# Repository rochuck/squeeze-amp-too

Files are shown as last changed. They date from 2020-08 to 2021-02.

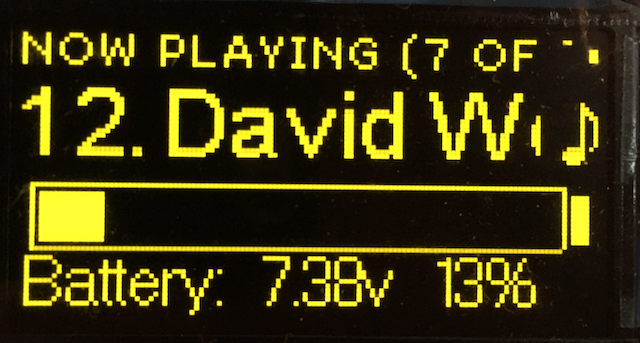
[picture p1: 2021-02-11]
images/bat_gauge.png

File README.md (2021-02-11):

# SqueezeAmpToo: an all-in-one audio sub-system

The SqueezeAmpToo is designed by Dave Viberg and Chuck Rohs and was completely inspired by the [SqueezeAMP project](https://github.com/philippe44/SqueezeAMP) and the [SqueezeESP project](https://github.com/philippe44/squeezelite-esp32).

While this project borrows a lot from the SqueezeAmp, it has some differences for both reduced cost and added functionality. These include:
* only 2 cells supported for reduced power consumption/heat.
* larger board to add a better performing 1 inch <sup>2</sup> heat sink for 16V operation. The board is now basically the size of a dual 18650 battery pack.
* a cost reduced charger and buck regulator
* onboard USB to serial interface for easy initial programming along with a JTAG port.
* V2 fixes a charger wiring error, low voltage cutoff for 3.3v buck, headphone and powerjack footprints.
* V2 adds an optional spi display header, rotary encoder and button board with an I2C expander, a daughter board to drive ws2812s, a battery pack thermister, and IR remote control daughter board.

The squeeze amp board is running in the box show below.  To run this board, in particular the RGB LEDs and I2C buttons on the gpio expander, the [SqueezeAmpToo Software](https://github.com/rochuck/squeezelite-esp32/tree/squeezetoo) should be used. This software is a fork of the SqueezeEsp project referenced above.

The RGB LEDS are illustrated in the animated GIF (it will only loop once in certain browsers, click on the image to see it in action if it isn't animating). This little box has 31 ws2812's (144 leds/meter density) along with the very nice/quasi expensive ssd1322 256 x 64 OLED.  While the leds might be a little bit hokey, the center led changed color to indicate the battery voltage. This is all described in the [Readme](https://github.com/rochuck/squeezelite-esp32/blob/squeezetoo/README.md).

 LED VU meters

# Future Plans
We've got a [PurePath Console Motherboard](https://www.ti.com/tool/PUREPATH-CMBEVM) board on order, so we can use the onboard DSP of the TAS chip.  This will allow us to stop messing with the equalizer running on the ESP and hopefully tune the stereos to get the most out of the speakers. 

We've done some playing around with a mono version of the board.  It is easy to hack to make it work that way, but again, the purepath software is probably required to do a proper job of it.

# Doc Packages,Gerbers, BOM, and Software
We're using Protel 99SE for schematics and routing. The current version, V2, files are here, use at your own risk, we have not yet done a board run on these files. Also if you use them, please give credit to Dave Viberg, Chuck Rohs, and [philippe44](https://github.com/philippe44) from whom we leveraged the initial schematics. Standing on the shoulders of giants and all that....

 V2 SqueezeAmpToo Doc Package

 V4 DaughterBoards Doc Package

 The [CAM PACKAGE](https://github.com/rochuck/squeeze-amp-too/tree/master/CAM-SqueezeAmpTooV2-panel-url) is here.

 The [BOM](https://github.com/rochuck/squeeze-amp-too/blob/master/SqueezeAmpTooV1-BOM.xlsx) is here. Note however this is the V1 BOM. It does not contain the daughterboard parts, But should get you started.

 As stated above Software is [here](https://github.com/rochuck/squeezelite-esp32/tree/squeezetoo) and [here](https://github.com/rochuck/squeezelite-esp32/releases/tag/0.0.6-rgb-led-update-v4.0-SqueezeToo-squeezetoo).

## Errata
The pinouts for the IR receiver are wrong.  Pins 2 and 3 are transposed.

# History

This project started out from experimenting with the squeezeamp software. I first got it working with a [HiFiBerry]( https://www.hifiberry.com/docs/archive/connecting-power-supply-and-speakers-to-the-hifiberry-amp/) clone. From there it got out of hand and we started building hardware and modifying software and ended up with the current generation board. 

## HiFiBerry Prototype
This design was prototyped using the squeezelite-esp32 code on a WROVER board that was fly-wired to a clone of the HiFiBerry AMP+. This audio board uses the TAS5713, and as such an appropriate driver needed to be written to use the squeezelite-esp32 code. That is now all ancient history but the picture and development is documented here for posterity (covered in CNC router dust):

  HifiBerry with SqueezeESP

For anyone else wanting to replicate this configuration, The WROVER is hooked up to the HiFiBerry as follows:

|WROVER Pin#|HiFiBerry 40pin connector number|Function|
|----|----|---|
|8|40|I2S-SD|
|9|12|I2S-CLK|
|10|35|I2S-LRCLK|
|11|5|I2C-SCL|
|12|3|I2C-SDA|
|1|6|GND|

Depending on your dev board, you may be able to pull power from the pi amp, but I would recommend separate power supplies, and just tie the grounds together.

As of this writing [sle118's repo](https://github.com/sle118/squeezelite-esp32/tree/c78c66faf57f0aea6eb86f7e74e01c9b28b824be) contains the TAS5713 driver I developed.
To test this out I used the sdkconfig "SqueezeAmp8MBFlash-sdkconfig.defaults". 
The code [here](https://github.com/sle118/squeezelite-esp32/blob/c78c66faf57f0aea6eb86f7e74e01c9b28b824be/components/squeezelite/output_i2s.c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)
was modified to replace "CONFIG_DAC_CONFIG" with "NULL"
so that the dac_config NVS parameter would not be overridden.

The dac_config was set to:
  - model=TAS5713,bck=33,ws=25,do=32,sda=27,scl=26

Also note that the partition map needed to be changed so that the OTA application resides at 0x160000.

## Squeeze Amp Too V1 Prototype
Since then, the V1 squeeze-amp-too has been built, and while there are a few errors, it performs remarkably well. The (modified for mono) V1 board is pictured here:

 squeeze-amp-too v1

It includes the following:

- Espressif's WROVER board based on ESP32 WiFi/BT chipset (built-in antenna)
- WiFi / BT connectivity
- TI's TAS575x stereo class-D amplifier for up to 2x20W
- 1"^2 heatsink to handle the TAS and WROVER heat
- Built-in battery charger 2 Li-ion cells in series and automatic switch between battery and external power
- Direct speaker output
- Jack 3.5mm for analogue line-out with insertion detection
- SDPIF optical output
- Connectors for GPIO
- Onboard CP2102N for programming, with rx/tx leds. (CP2102 must be programmed with silabs software for the leds to work, i.e. chaning the gpios for alternate functionality)
- Charge LED 
- Two general purpose LEDs (red/green)

Connectors:
- J1 - Power Jack rated for 5A (PJ-047AH)
- J2 - Headphone Jack
- J3 - USB Micro B (for initial programming/debug)
- J4, J9 - Battery connectors
- J10 - .15" header, alt power
- J5, J12 - .15" speaker connectors
- J6, J13 - 5 pin .1" headers, for various gpio.
- J7 - 4 pin .1" header for sh1105 OLED display
- J11 - 6 pin .1" header for JTAG

## What can it do

With the squeezelite-esp32 software, you can (as quoted from the SqueezeAMP)

- Stream from LMS and send audio to the build-in amplifier, the line-out jack, the spdif connector or another bluetooth speaker. You can also use an external I2S DAC if you connect it to the general purpose 5/8 pins connector and tweak the software. Synchronization works.
- Stream from a Bluetooth device and send audio to the same outputs, except of course for sending to another bluetooth speaker ... There is no guarantee of audio/video synchronization at this point
- Stream from an AirPlay1 device (iPhone, iTunes ...) to the same outputs, including to a bluetooth speaker. Synchronization works.
- Add your own buttons, rotary encoder and map/combine them to various functions (play, pause, volume, next ...
- Use IR control by adding a simple receiver compatible with 38kHz device (no pullup resistor or capacitor needed)
- Add a display like this [one](https://www.buydisplay.com/i2c-blue-0-91-inch-oled-display-module-128x32-arduino-raspberry-pi) which can be directly connected to the 6-pins header. Currently, SSD1306, SSD1326/7 and SH1106 displays are supported.
- Support for WS2812 RGB LED VU meters (other coming soon). Supported with a 5v buck converter with enable
- Rotary encoder daughter board with IIC/SPI gpio expanders

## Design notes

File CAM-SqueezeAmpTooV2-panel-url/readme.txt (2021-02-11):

CAM Outputs Generation Report
for 'CAM Outputs for SqueezeAmpTooV2-panel.cam'
at 21:40:26 on 26-Sep-2020

'Pick Place Output 1'
'Pick Place for SqueezeAmpTooV2-panel.txt' generated
'Pick Place for SqueezeAmpTooV2-panel.csv' generated

'NC Drill Output 1'
'SqueezeAmpTooV2-panel.TXT' generated text drill file
'SqueezeAmpTooV2-panel.DRL' generated binary drill file
'SqueezeAmpTooV2-panel.DRR' generated tool list

'Gerber Output 1'
'SqueezeAmpTooV2-panel.GTL' generated top copper
'SqueezeAmpTooV2-panel.GBL' generated bottom copper
'SqueezeAmpTooV2-panel.GTO' generated top silkscreen
'SqueezeAmpTooV2-panel.GBO' generated bottom silkscreen
'SqueezeAmpTooV2-panel.GTP' generated top solder paste
'SqueezeAmpTooV2-panel.GBP' generated bottom solder past
'SqueezeAmpTooV2-panel.GTS' generated top solder mask
'SqueezeAmpTooV2-panel.GBS' generated bottom solder mask
'SqueezeAmpTooV2-panel.GM4' generated board outline
'SqueezeAmpTooV2-panel.GPT' generated top pad master
'SqueezeAmpTooV2-panel.GPB' generated bottom pad master
'SqueezeAmpTooV2-panel.REP' generated

Total number of generated files = 17

Board specification
FR-4 or FR-4 high TG
double sided 1oz. copper
thickness, choose 0.8mm to 1.6mm
trace space 0.006"/0.006"
smallest drill 0.012"
solder mask, any color you want
silkscreen, any color you want

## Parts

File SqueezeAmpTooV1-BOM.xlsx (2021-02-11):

BOM-SqueezeAmpTooV1, David Viberg, May 25, 2020
Used | Part Type | Designator | Footprint | Description | DigiKey
==== | ============== | ========== | ========= | =================== | ==========
Resistors
1 | 0.1R | R17 | 0805 | Resistor sets charging current | 273-KDV08FR100ETCT-ND
1 | 1K | R22 | 0603 | Resistor
10 | 10K | R1 R2 R3 R4 R5 R6 R7 R20 R23 R24 | 0603 | Resistor
1 | 13K | R18 | 0603 | Resistor
1 | 22.1K | R19 | 0603 | Resistor
1 | 40,2K | R16 | 0603 | Resistor
1 | 47.5K | R21 | 0603 | Resistor
1 | 59K | R9 | 0603 | Resistor
2 | 100K | R14 R15 | 0603 | Resistor
1 | 150K | R13 | 0603 | Resistor
1 | 174K | R11 | 0603 | Resistor
1 | 499K | R10 | 0603 | Resistor
1 | 750K | R12 | 0603 | Resistor
1 | 3M | R8 | 0603 | Resistor
Thermister
1 | 10K THERMISTOR | RT1 | 0603 | thermister, ntc | 490-16279-1-ND
Capacitors
1 | 47pF | C38 | 0603 | Capacitor
8 | 100nF | C1 C2 C3 C6 C7 C8 C9 C41 | 0603 | Capacitor
4 | 220nF 25V | C30 C31 C32 C33 | 0603 | Capacitor
4 | 680nF 25V | C34 C35 C36 C37 | 0603 | Capacitor
9 | 1uF 25V | C5 C18 C19 C20 C21 C22 C23 C24 C25 | 0603 | Capacitor
4 | 2.2uF 25V | C26 C27 C28 C29 | 0603 | Capacitor | 490-12738-1-nd
5 | 10uF 16V | C4 C16 C17 C39 C40 | 0603 | Capacitor | 1276-6769-1-ND
6 | 22uF 25V | C10 C11 C12 C13 C14 C15 | 0805 | Capacitor | 311-1903-1-nd
Inductors
4 | 4.7uH 4.5A | L1 L2 L3 L4 | 2424 | Inductor for speaker filters | 2037-sdes064t-4r7msct-nd
2 | 6.8uH 2A | L5 L6 | 2020 | Inductor for charger | 587-3462-1-nd
Diodes
3 | SCHOTTKY 30V 3A | D1 D2 D3 | DO-214AC | Schottky Diode pmeg3030 | 1727-5324-1-nd
3 | red | D4 D5 D6 | 0603D | red LED | generic 200 mcd
2 | grn | D7 D8 | 0603D | green LED | generic 200 mcd
Transistors
3 | mmbt4401 | Q1 Q2 Q3 | SOT-23 | NPN transistor
1 | PFET dmp4065 | Q4 | SOT-23 | MOSFET P SOT-23, 2.4A | DMP4065S-7DICT-ND
Connectors
1 | POWERJACKCOAX | J1 | PJ-047AH | Power Jack COAX, 5A | CP-047AH-ND
1 | SJ-43514 | J2 | SJ-43514 | Headphone jack | CP-43514-ND
1 | USB-MICRO-B-JACK | J3 | USB-MICRO-B-FCI-10118194 | USB micro B jack | 609-4618-1-nd
3 | CON2 | J4 J8 J9 | HDR2 | Connect 2 batteries and switch
3 | CON2 - horizontal | J5 J10 J12 | HDR2-.15 | speaker terminals, alt power | 732-2088-ND
3 | plug for above |  |  | speaker terminals, alt power | 609-3797-ND
2 | CON5 | J6 J13 | HDR5 | Connector for gpio's w pwr gnd | solder pigtails
1 | CON4 | J7 | HDR4 | 4 x 0.1" pin jack for sh1106 oled
1 | CON6 | J11 | HDR6 | Connector for esp32-prog jtag | solder pigtails
Battery
2 | 18650 | J4 J8 |  | 18650 Li Ion cells
1 |  |  |  | dual 18650 battery holder | 1597-114090053-nd
Switches
1 | SW-SPDT | S1 | SW-EG1270 | slide switch | EG1847-ND
1 | SW-PB-GND | S2 | SWKMR2 | push button reset | 401-1427-1-ND
Solder Bridge
1 | Solderbridge | BR1 | solderbridge0.05 | solder bridge to disconnect IRRX when doing JTAG
IC's
1 | TAS5754M | U1 | SSOP-48 | Stereo class D amplifier | 296-40564-1-ND
1 | ESP32-WROVER | U2 | ESP32 | ESP32 dual core micro w wifi | 1904-1034-1-ND
1 | EAPLTAA4 |  | PLT133/T10W | SPDIF transmitter | 1080-1524-ND
1 | AP65111 | U4 | SOT-23-6 | Sync buck, 4-18Vin, 1.5Aout | ap65111awu-7dict-nd
1 | MP2615 | U5 | QFN-16-MPS | 1-2 cell Li-ion battery charger | 1589-1610-1-nd
1 | CP2102-24 | U6 | QFN-24-.5mm | Usb to serial interface adapter | 336-5887-ND
1 | TSOP77238TT | U7 | TSOP77238 | 38KHz IR receiver | tsop77238ttct-nd

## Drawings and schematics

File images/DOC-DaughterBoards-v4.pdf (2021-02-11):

## Daughterboards V4 by David Viberg. Aug 6, 2020 MIT License

## In collaboration with Chuck Rohs / Zethus Information Systems

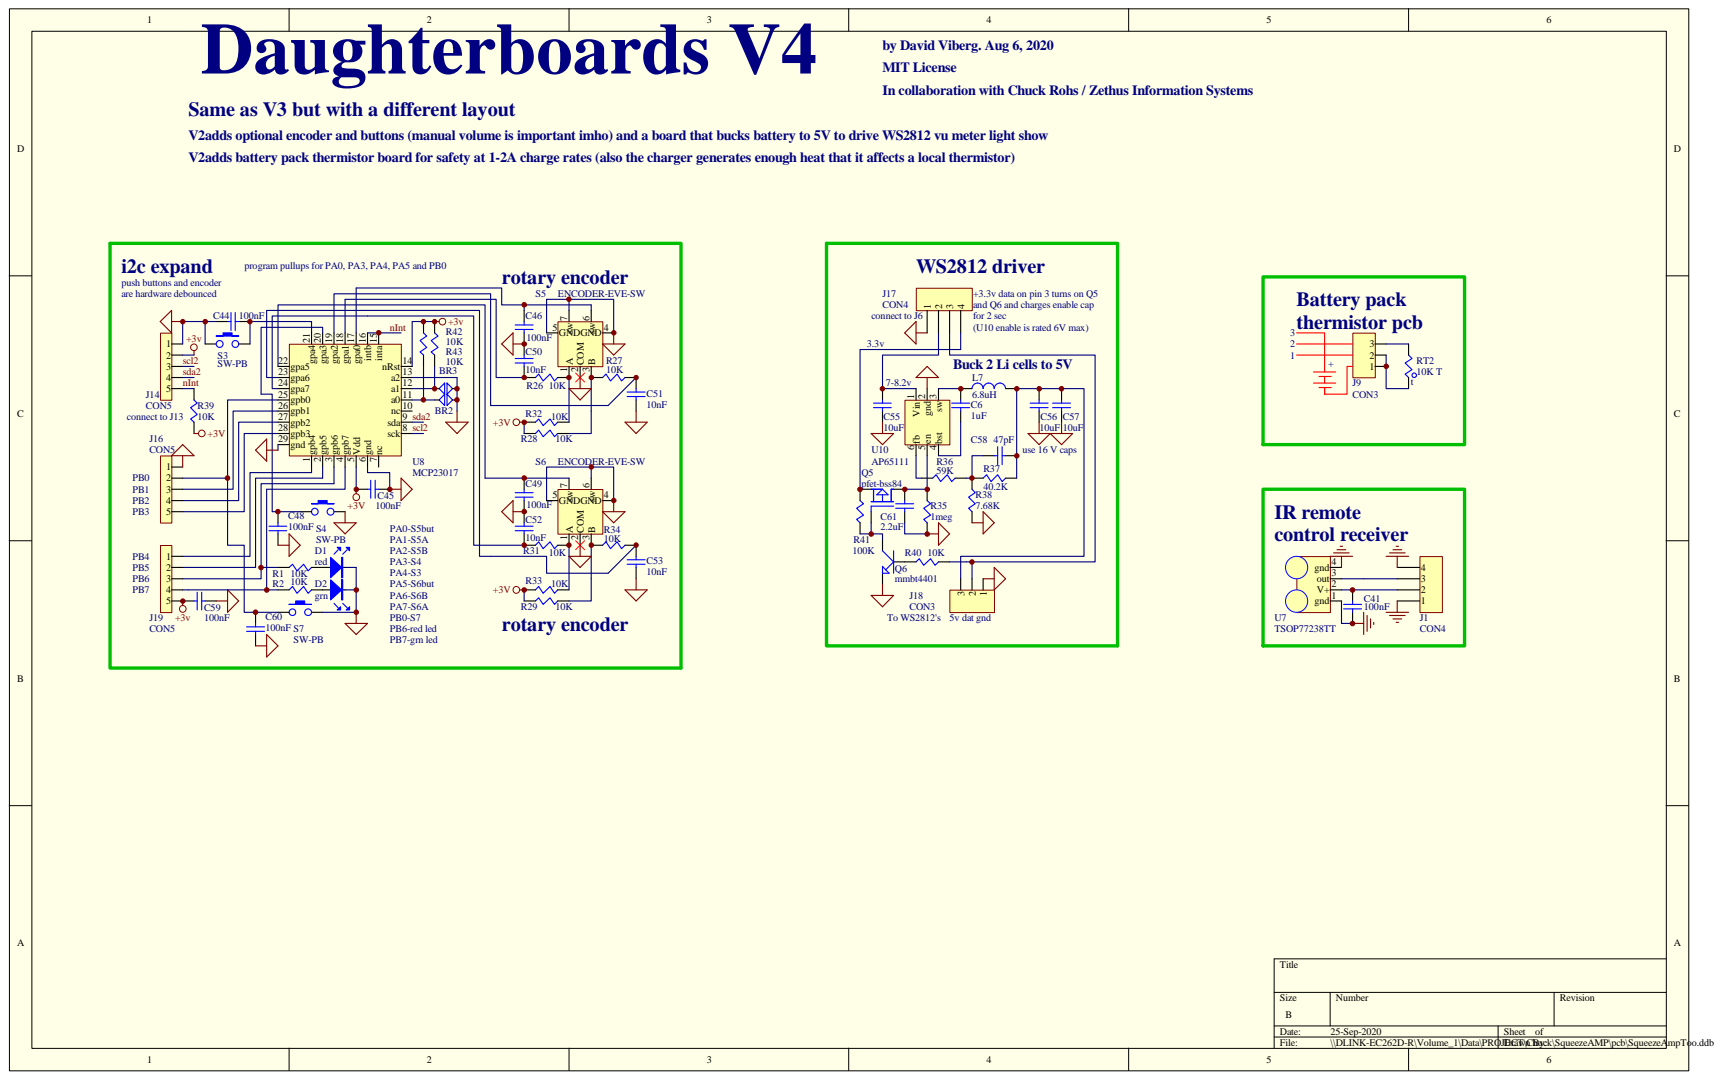
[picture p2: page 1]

Same as V3 but with a different layout
V2adds optional encoder and buttons (manual volume is important imho) and a board that bucks battery to 5V to drive WS2812 vu meter light show
V2adds battery pack thermistor board for safety at 1-2A charge rates (also the charger generates enough heat that it affects a local thermistor)

program pullups for PA0, PA3, PA4, PA5 and PB0

push buttons and encoder
are hardware debounced

+3.3v data on pin 3 turns on Q5
and Q6 and charges enable cap
for 2 sec
(U10 enable is rated 6V max)

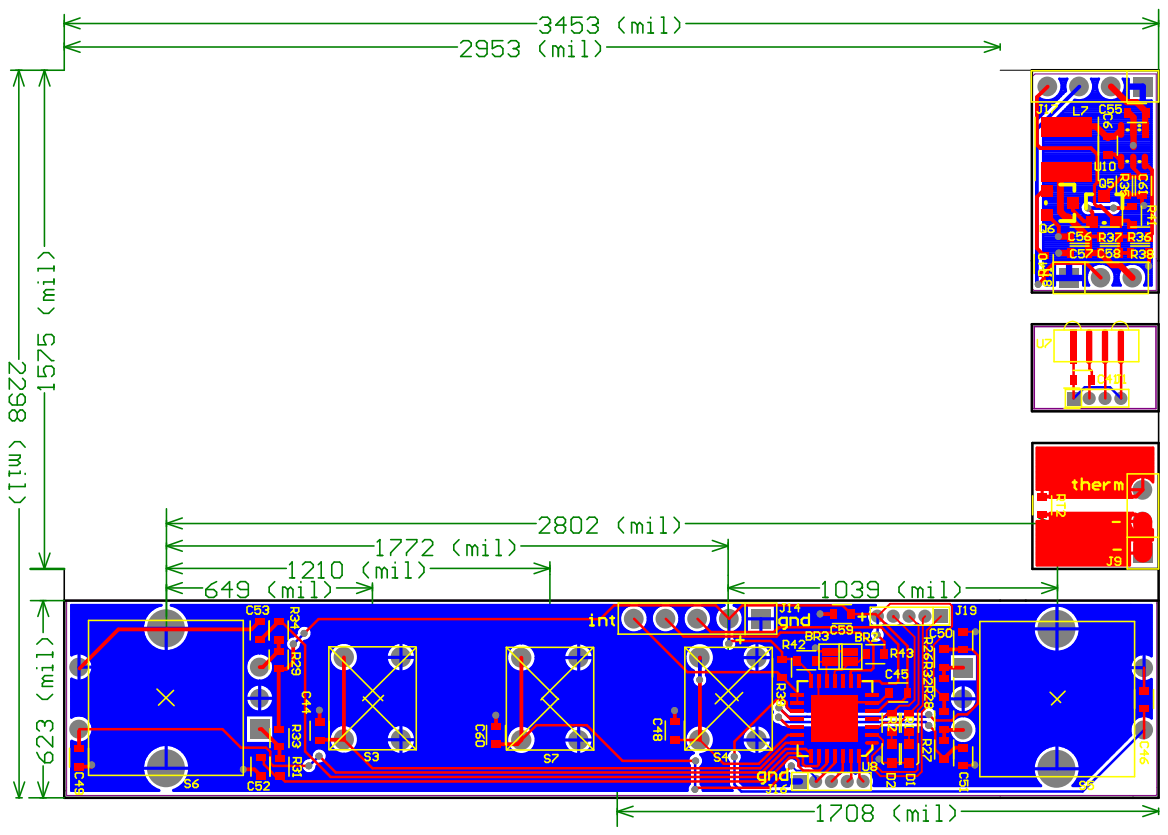
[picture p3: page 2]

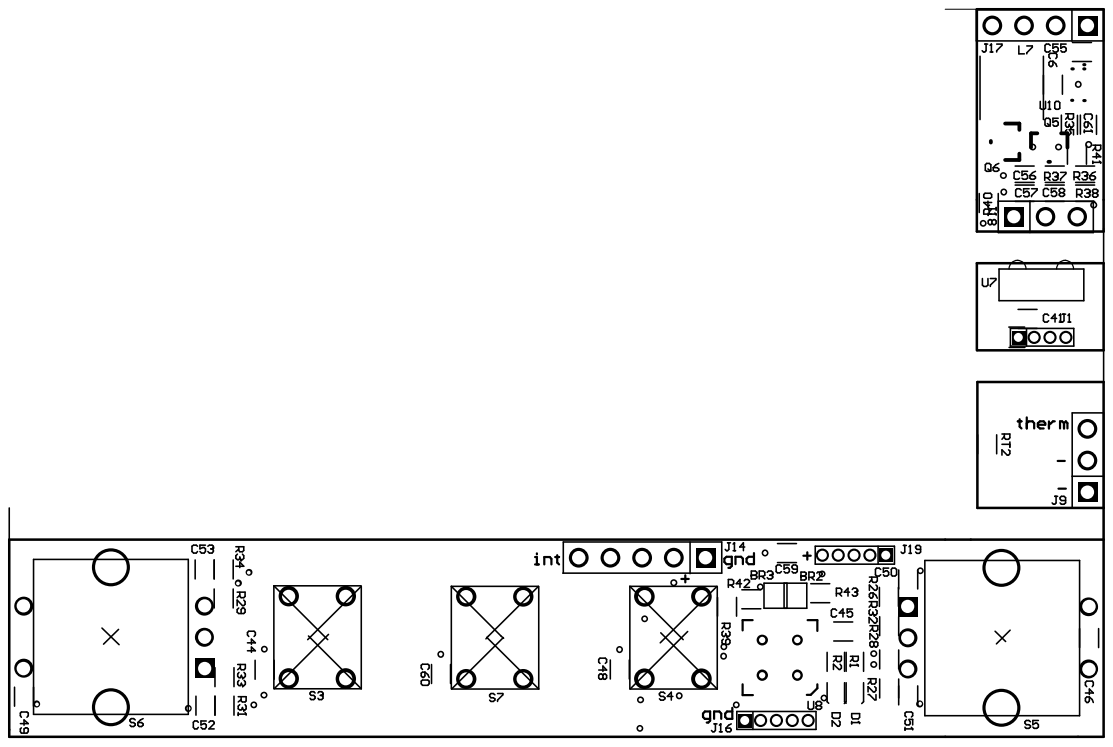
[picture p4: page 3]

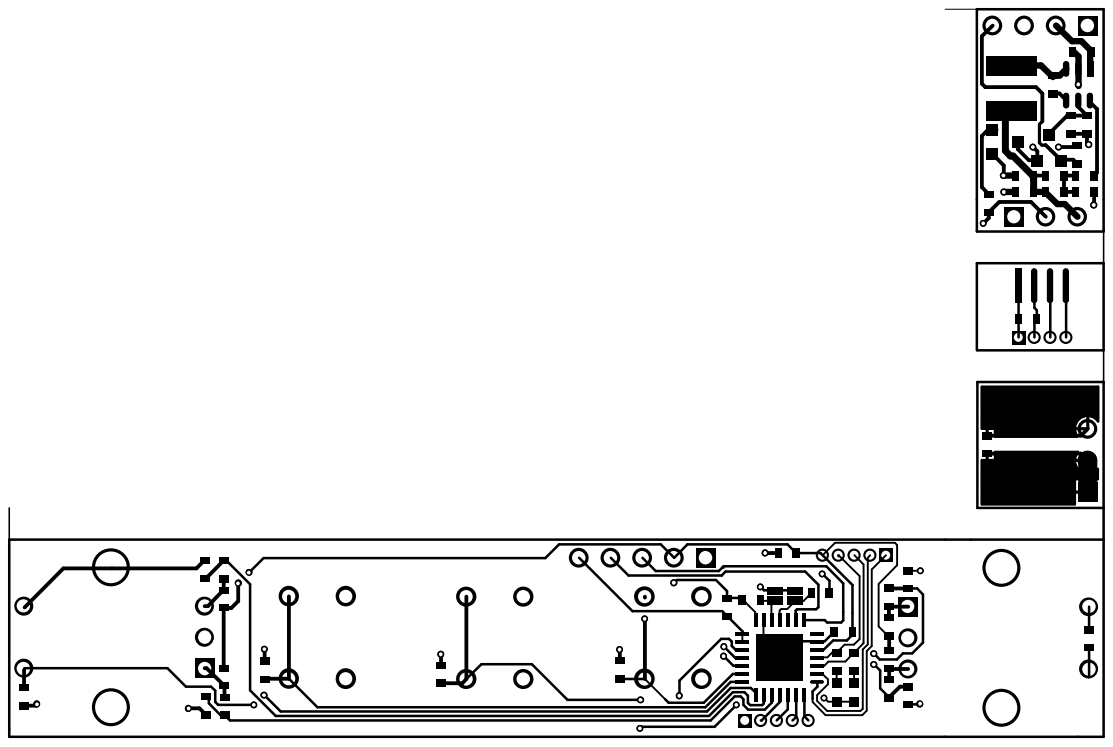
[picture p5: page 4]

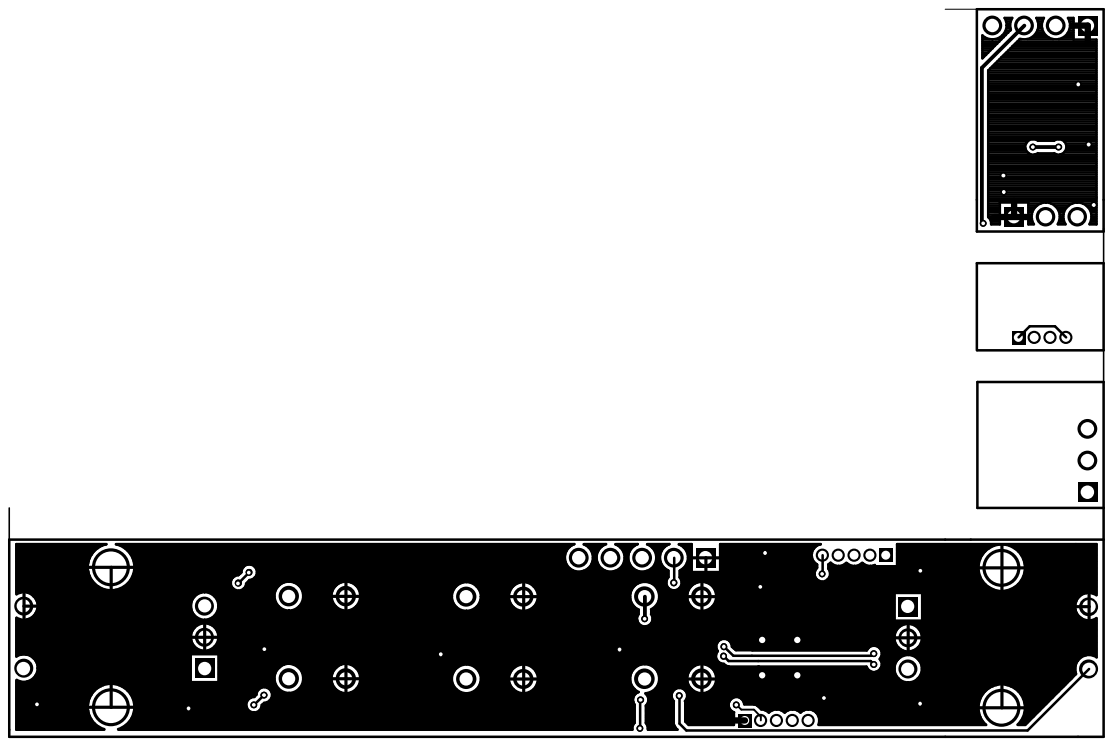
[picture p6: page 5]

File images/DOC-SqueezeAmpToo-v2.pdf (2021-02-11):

# SqueezeAmpToo V2

## by David Viberg. Aug 6, 2020

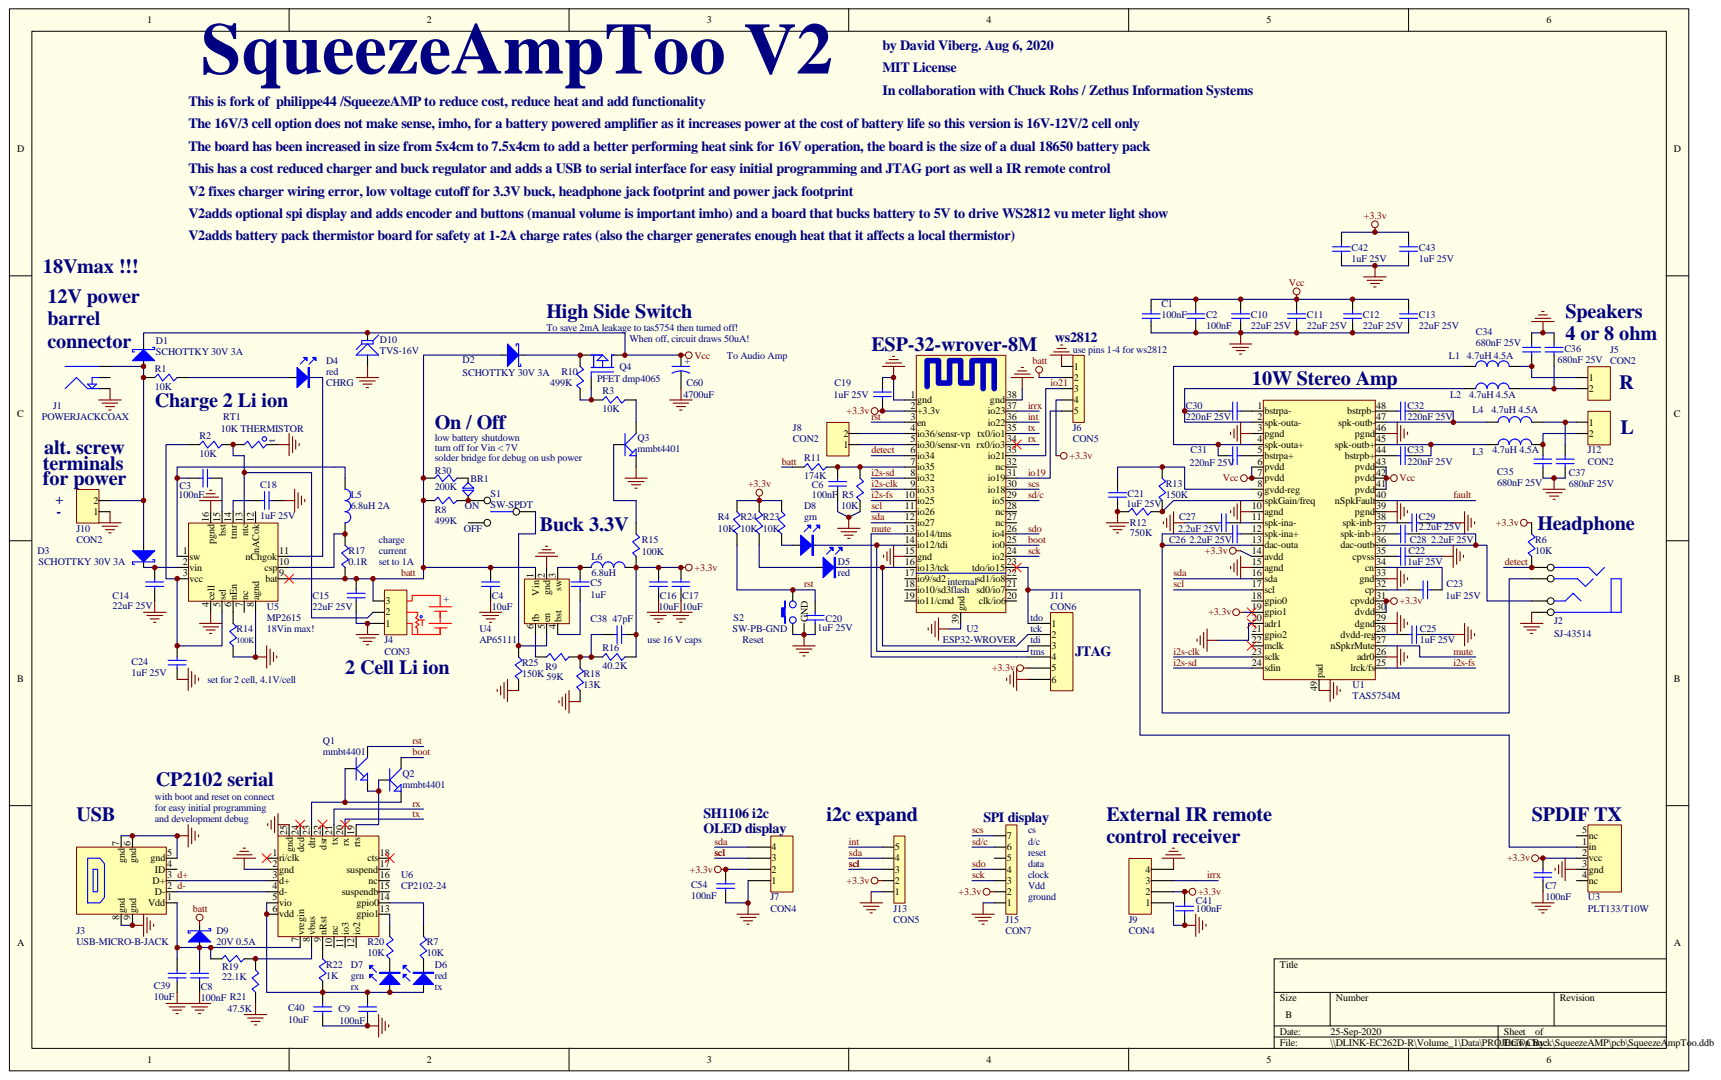
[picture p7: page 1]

MIT License
In collaboration with Chuck Rohs / Zethus Information Systems

This is fork of philippe44 /SqueezeAMP to reduce cost, reduce heat and add functionality
The 16V/3 cell option does not make sense, imho, for a battery powered amplifier as it increases power at the cost of battery life so this version is 16V-12V/2 cell only
The board has been increased in size from 5x4cm to 7.5x4cm to add a better performing heat sink for 16V operation, the board is the size of a dual 18650 battery pack
This has a cost reduced charger and buck regulator and adds a USB to serial interface for easy initial programming and JTAG port as well a IR remote control
V2 fixes charger wiring error, low voltage cutoff for 3.3V buck, headphone jack footprint and power jack footprint
V2adds optional spi display and adds encoder and buttons (manual volume is important imho) and a board that bucks battery to 5V to drive WS2812 vu meter light show
V2adds battery pack thermistor board for safety at 1-2A charge rates (also the charger generates enough heat that it affects a local thermistor)

35 dac-outb 36 spk-inb+37 spk-inb-38 pgnd39 nSpkFault40 pvdd41 pvdd42 pvdd43 bstrpb+44 spk-outb+45 pgnd46 spk-outb-47 bstrpb-48

To save 2mA leakage to tas5754 then turned off!

When off, circuit draws 50uA!

low battery shutdown
turn off for Vin < 7V
solder bridge for debug on usb power

lrck/fs25 adr0 26 nSpkrMute27 dvdd-reg28 dgnd29 dvdd30 cpvdd 31 cp

set for 2 cell, 4.1V/cell

with boot and reset on connect
for easy initial programming
and development debug

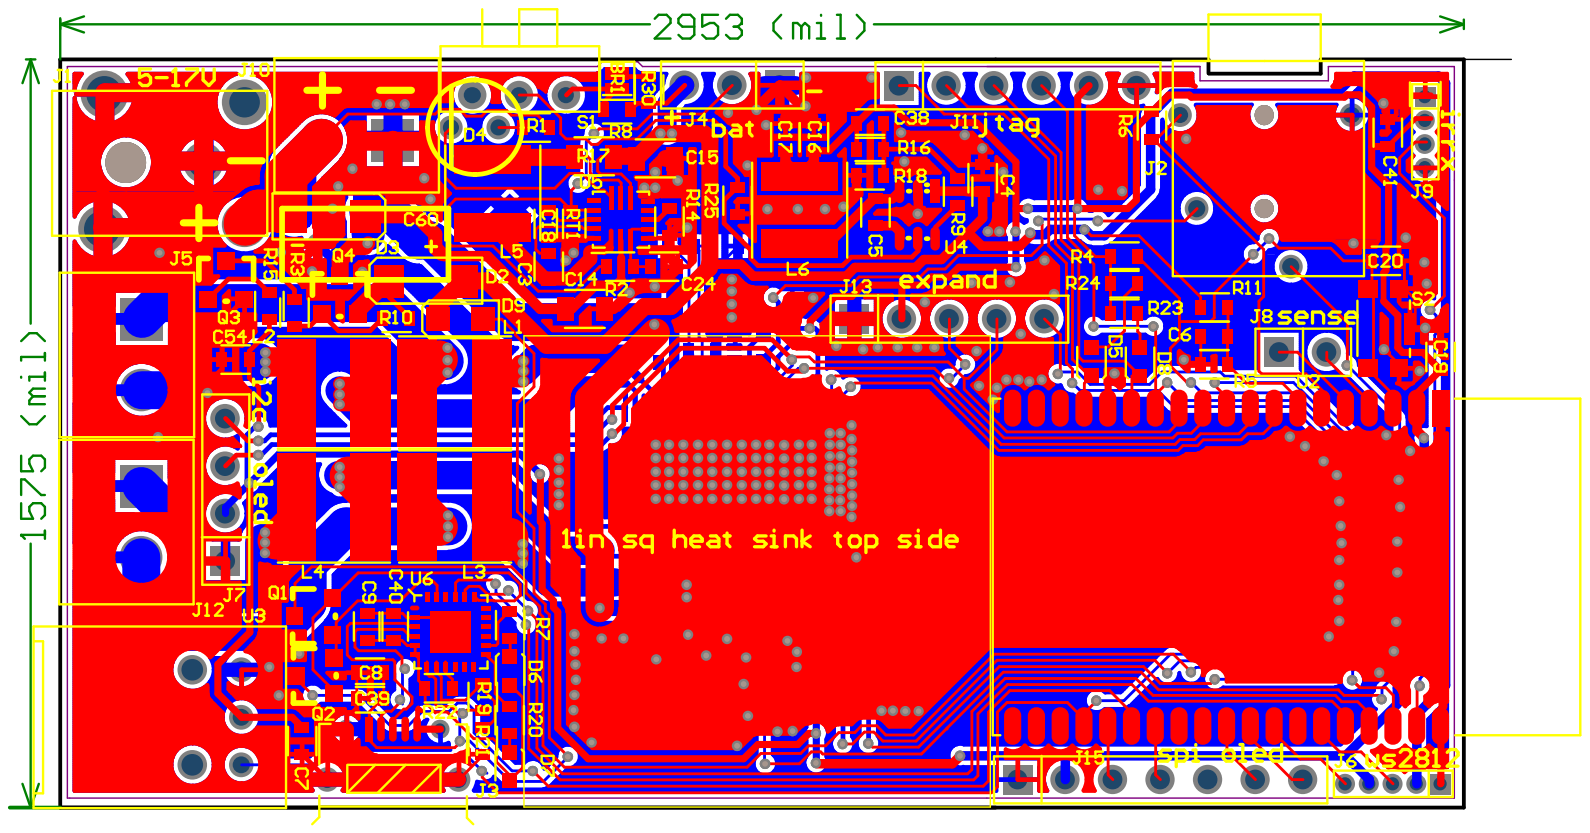
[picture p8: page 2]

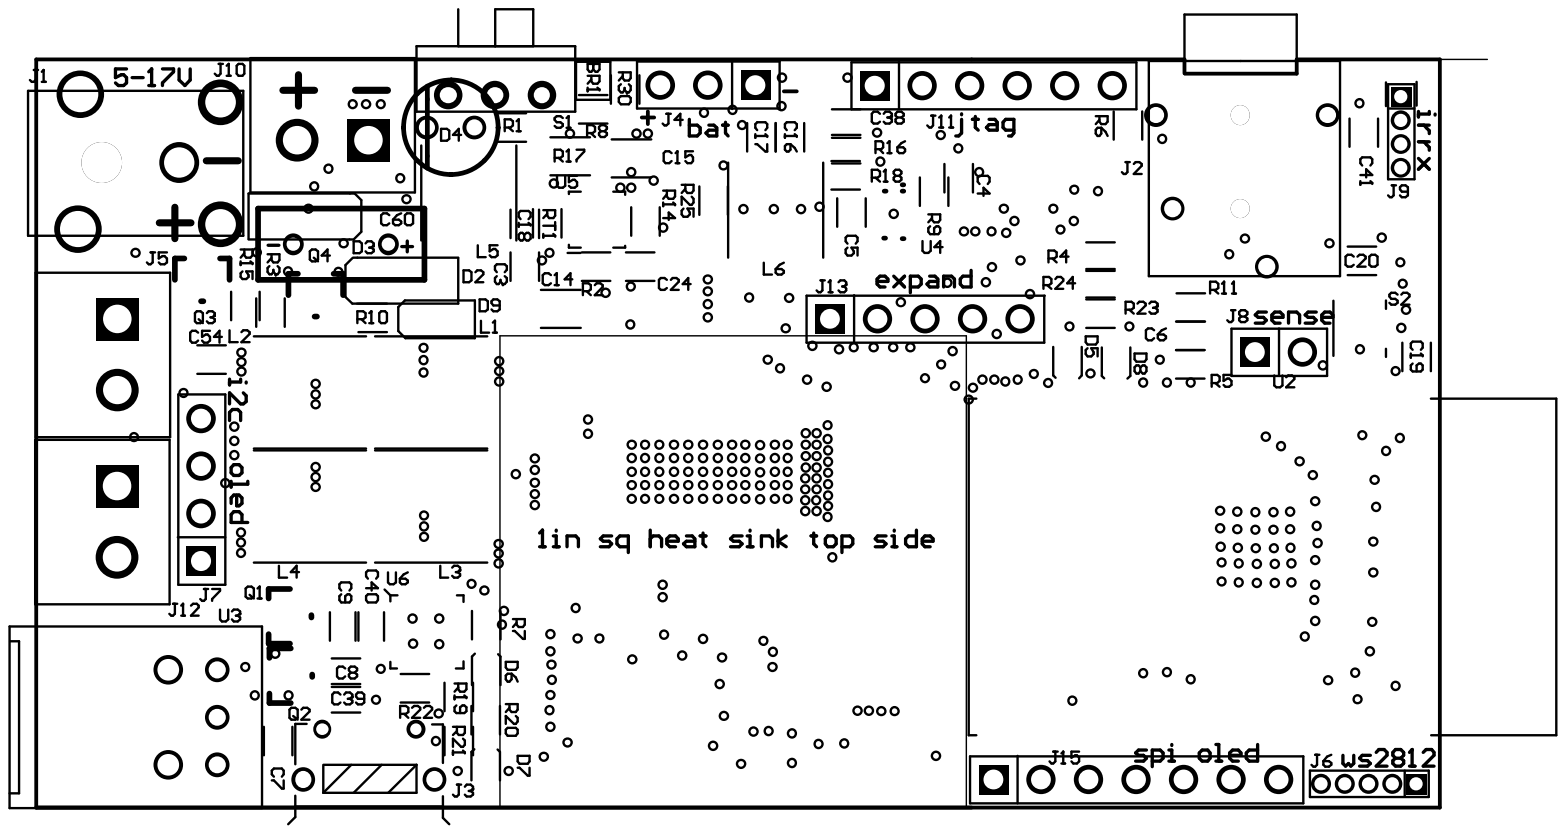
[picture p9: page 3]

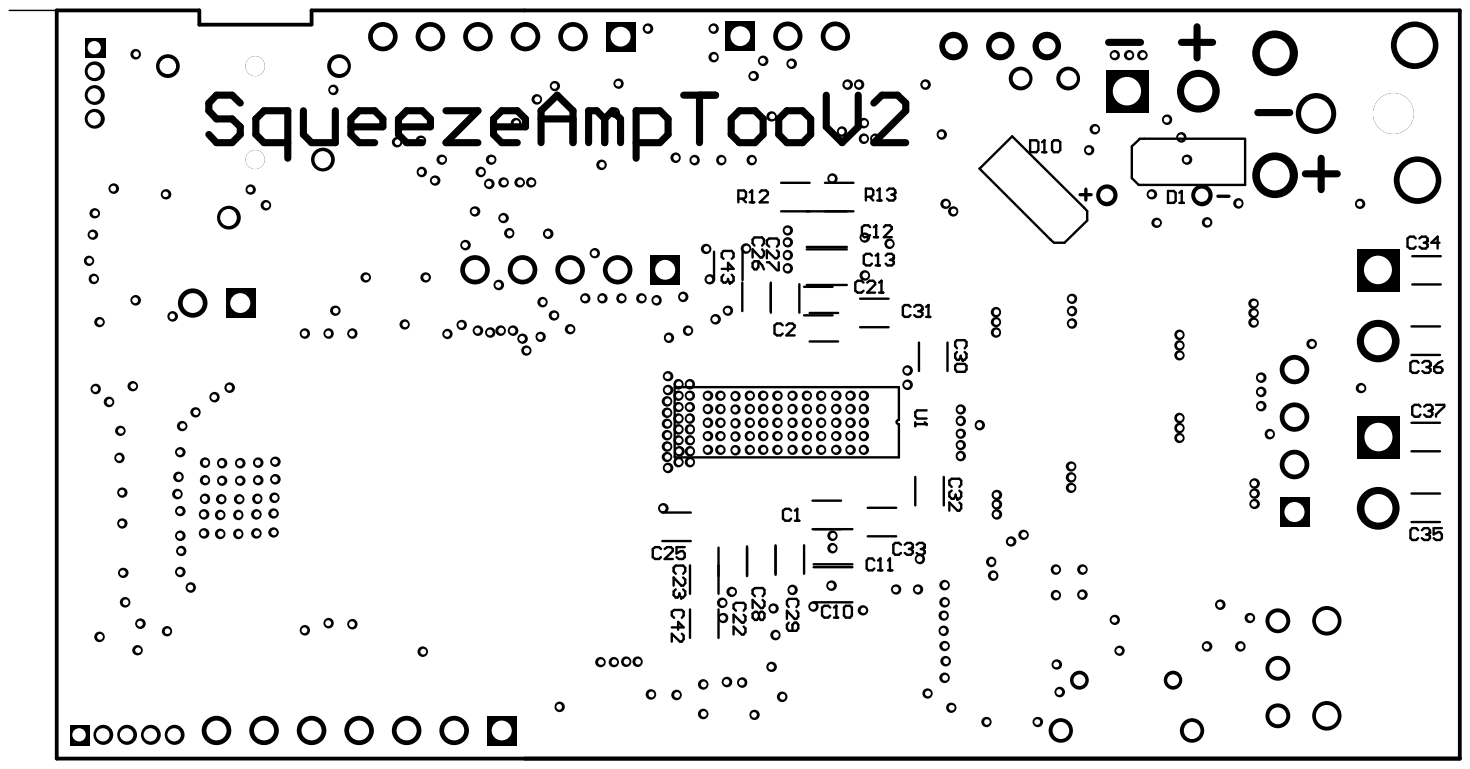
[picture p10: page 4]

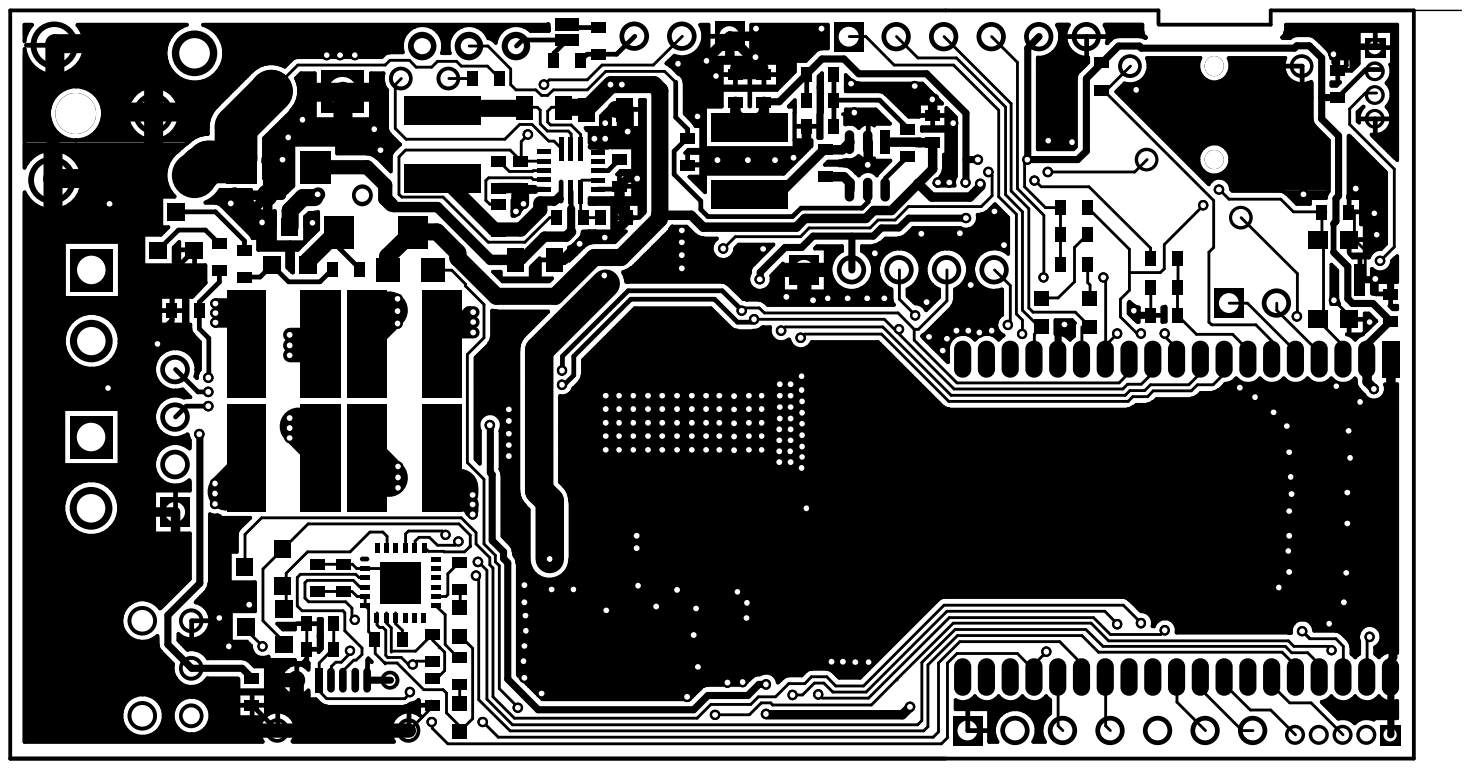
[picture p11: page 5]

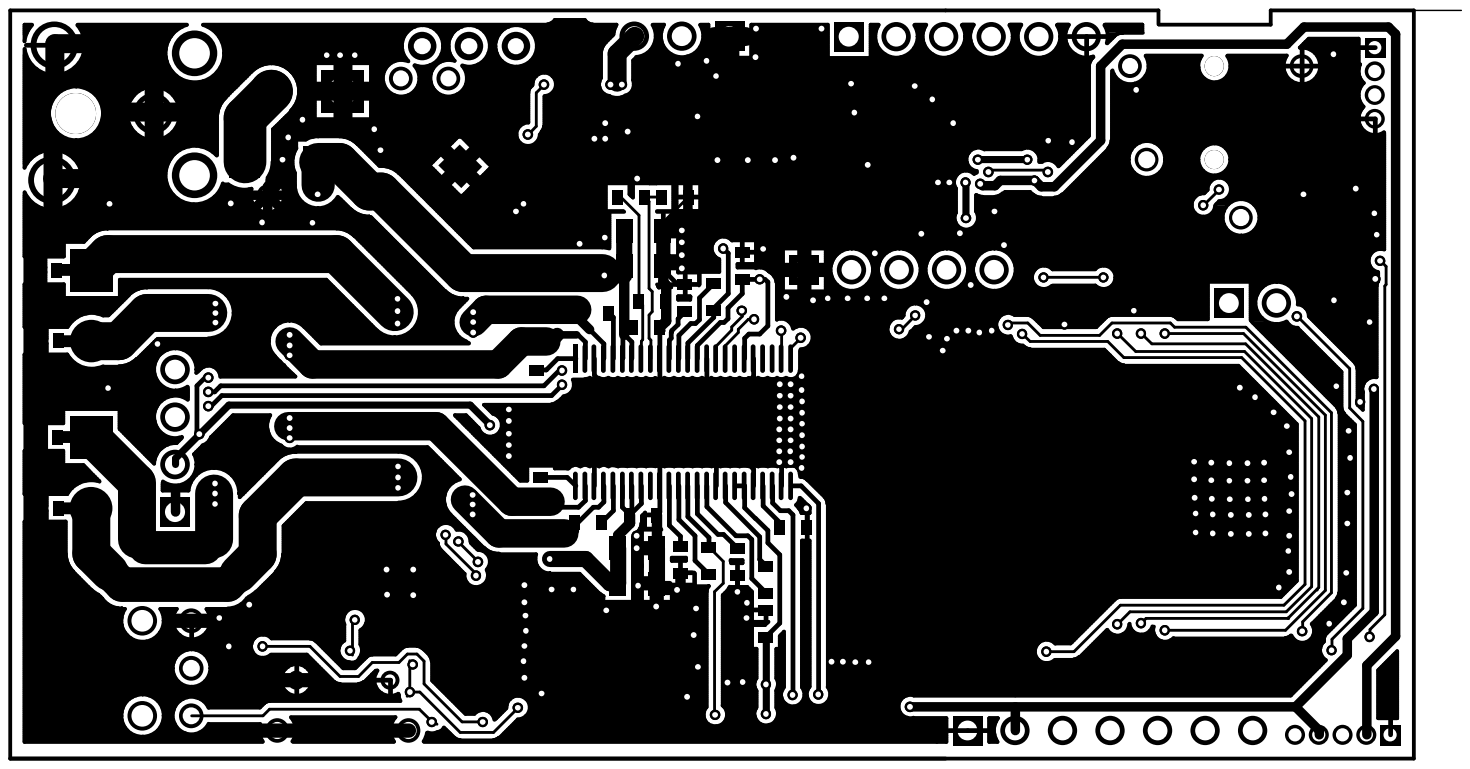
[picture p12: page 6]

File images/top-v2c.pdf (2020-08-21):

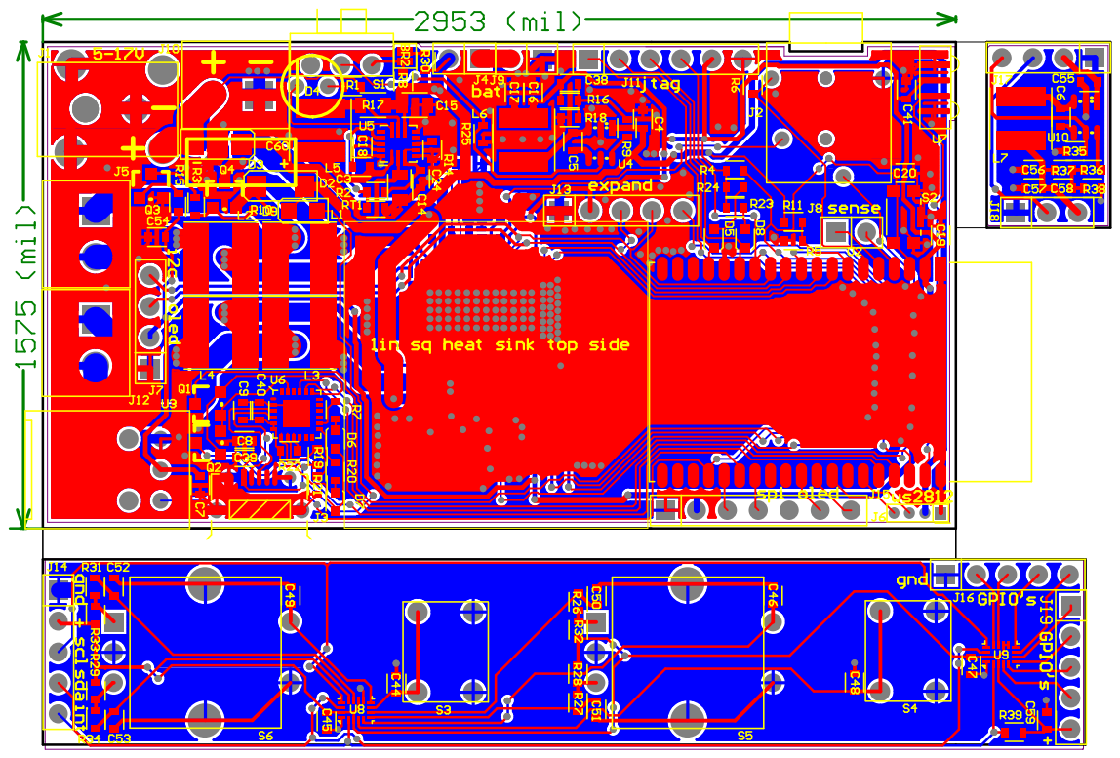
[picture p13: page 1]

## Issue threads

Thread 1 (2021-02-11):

No issue, really

philippe44, 2021-02-11:
Hi - Have you been building other units? I've retrofitted (hacked) a SB3 and I'm thinking of making a proper PCB for that. There is a perfect 5.5 OLED display. Any advice?

Cheers

rochuck, 2021-02-11:
I've done a few,  all my units are custom.  I've added a picture of one of my [players](https://github.com/rochuck/squeeze-amp-too/blob/master/images/squeezeball.png). This is a squeezeamp in the case that the i9 comes in.  I've got one of the 5.5in ssd1322 displays on order to try out.  I'm not really sure what you are asking advice on... My experiences so far are to stick with SPI displays, since the i2c seem glitchy. The TAS chip doesn't always initialize when one of those displays is hooked up.  I'm not sure if there is too much contention on the bus with multiple devices or what.
I also like the IR remote.  I've got the i2c gpio expander in my v2 board and associated code.  I know it works but have not actually used it in a box that was not just a prototype. you might be interested in that, although I don't think the SB3 has buttons.

I used to use dirtypcb for making boards but I think you can get better prices elsewhere these days.

If you can be more specific I can give you a better answer.

philippe44, 2021-02-11:
It's just that I feel you're better than me at board design so I might ask for some review or advices, especially around the analogue and the power management parts

rochuck, 2021-02-11:
Ok, no problem. I mostly concentrate on software and work with a fellow hardware engineer. We would be happy to answer any questions you may have.  The battery charging chip that we use works really well but is very sensitive to the layout if you choose to borrow from our design. Just an FYI.

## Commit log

2020-08-05 update with details on how to run the hifiberry with squeezelite-esp32
2020-10-20 update to V2
    [Pick Place for SqueezeAmpTooV2-panel.csv, SqueezeAmpTooV1-BOM.xlsx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]
2020-11-10 Add files via upload
    battery gas gauge image
